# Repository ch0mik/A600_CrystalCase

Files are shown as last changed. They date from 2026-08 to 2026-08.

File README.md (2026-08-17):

# A600Reborn + PiStorm16 CM4 acrylic enclosure

[Polska wersja](CZYTAJTO.md)

Flat CNC-cut enclosure panels for an Amiga 600 motherboard compatible with the
[A600Reborn](https://github.com/istedman/A600Reborn) project, a PiStorm16/CM4
with active cooling, a bottom-mounted 1 MB Chip RAM expansion and a
FrameThrower 600. Video is exposed through a full-size HDMI ribbon adapter and
bracket installed in place of the RF modulator.

> **Disclaimer:** This is an experimental, unverified mechanical design. I
> accept no responsibility for damage to equipment, data loss, injury, or any
> other loss resulting from its manufacture, assembly, or use. You build and
> use it entirely at your own risk. Verify every dimension, clearance, wiring
> connection, and electrical polarity on your own hardware before power-up.

> **Status: mechanical prototype.** The motherboard outline and connector
> positions come from KiCad, but no manufacturing drawings are publicly
> available for the HDMI bracket, Ami64 Gotek assembly or the exact CM4 cooler.
> Before cutting the final acrylic, make a test I/O panel from 1 mm cardboard
> or HDF and verify the dimensions listed below.

## Repository contents

```text
.
├── dxf_screws/          screw-fastened CNC files at 1:1 scale
├── dxf_simple_joinery/  simple Bramble Pi-style finger-joint variant
├── generate_dxf.py      dependency-free parametric generator
├── visualize_assembly.py deterministic DXF/KiCad 3D projection
├── renders/             generated SVG and PNG assembly views
├── .gitignore
├── README.md            English documentation
└── CZYTAJTO.md          Polish documentation
```

The generated DXF files are intentionally committed so they can be sent to a
manufacturer without installing Python. After changing parameters, regenerate
them with:

```powershell
python generate_dxf.py
```

The technical views in `renders/` are generated deterministically from the DXF
and source PCB rather than by an image generator. Rebuild both views with:

```powershell
python visualize_assembly.py --pcb C:\path\to\Amiga600.kicad_pcb
```

The command rebuilds both views of the finger-joint enclosure.

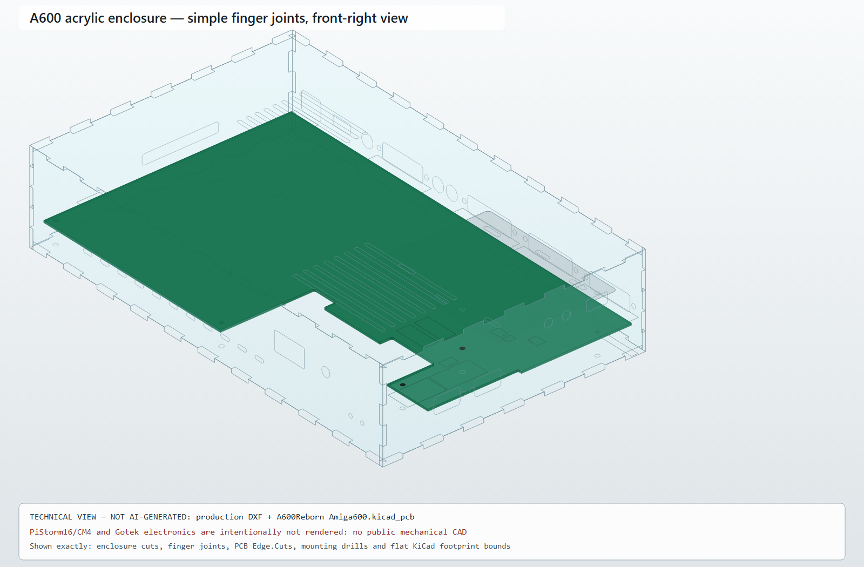
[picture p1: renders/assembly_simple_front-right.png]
Front-right assembly preview


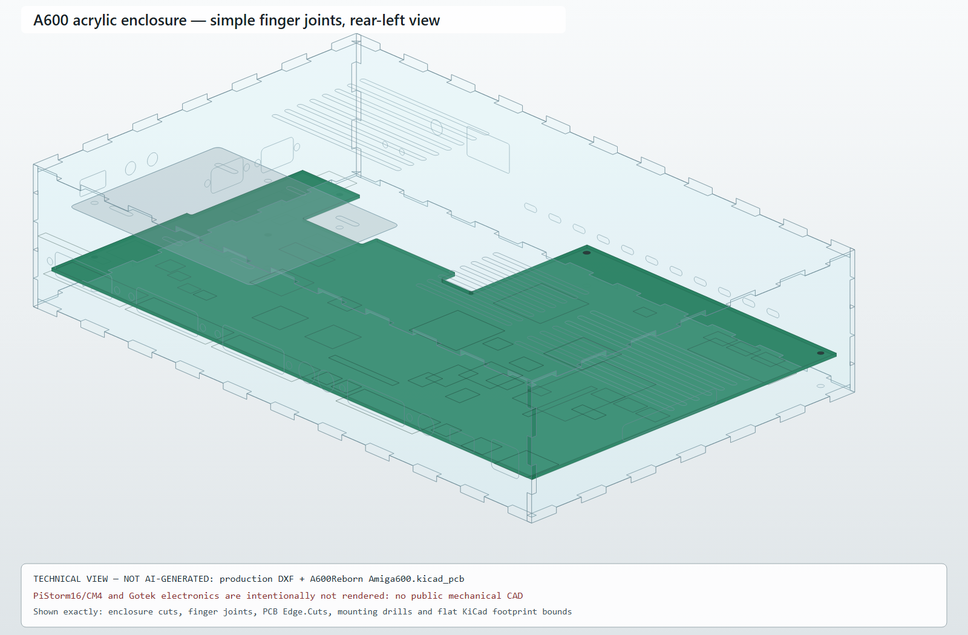
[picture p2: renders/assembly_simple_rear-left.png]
Rear-left assembly preview


> **AI disclosure:** The conceptual photorealistic image below was generated
> by AI from the supplied assembled A600 photo. It is visibly labelled in the
> image in line with the transparency principle described in the
> [European Commission's AI regulatory framework](https://digital-strategy.ec.europa.eu/en/policies/regulatory-framework-ai).

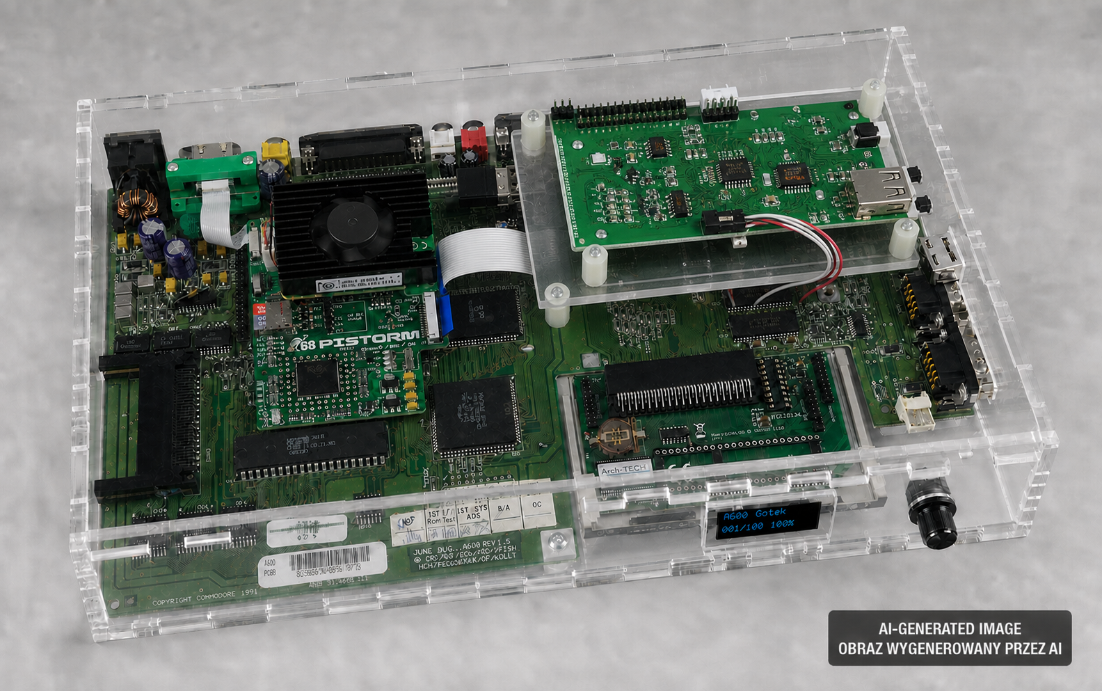
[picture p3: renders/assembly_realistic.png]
AI-generated conceptual photorealistic enclosure preview


The AI-generated image is illustrative only. It shows the requested bare Gotek
PCB on a carrier, with its USB and buttons at the right wall and the 0.96-inch
OLED/encoder at the front. Use the non-AI SVG/DXF technical views for dimensions
and manufacturing decisions.

Only geometry confirmed by the DXF/KiCad sources is shown. The PCB `Edge.Cuts`,
mounting-drill diameters and flat footprint bounds are read directly from the
KiCad file. No arbitrary component heights are assigned. PiStorm16/CM4 and
Gotek electronics are deliberately omitted because no public mechanical CAD
is available; the visualizer does not replace them with invented models.

## Production files

The `dxf_screws/` directory contains the screw-fastened variant:

- `01_bottom_3mm.dxf` — bottom plate, five motherboard mounting points and
  ventilation below the RAM expansion;
- `01b_bottom_gotek_3mm.dxf` — compatible Gotek bottom; the carrier shares
  motherboard H1/MT6 standoff axes and needs no extra bottom holes;
- `02_top_3mm.dxf` — top plate with PiStorm16 intake and exhaust ventilation;
- `02b_top_gotek_oled_rotary_3mm.dxf` — top with a 0.96-inch OLED window,
  rotary encoder and activity LED;
- `02c_top_gotek_external_box_3mm.dxf` — top with two ribbon-cable passages for
  the Ami64 external display box;
- `02d_top_gotek_carrier_above_cn11_3mm.dxf` — unpierced top for a Gotek
  mounted above CN11 on motherboard standoffs;
- `03_rear_io_1mm.dxf` — power, HDMI, composite, RGB, audio, serial, parallel
  and external floppy ports;
- `04_right_io_3mm.dxf` — two DE-9 mouse/joystick ports;
- `04b_right_io_floppy_3mm.dxf` — alternative side panel with a generic floppy
  drive opening;
- `04c_right_io_gotek_usb_3mm.dxf` — Gotek side panel with rear-positioned
  USB-A access and two 6.5 mm control-button openings;
- `05_left_pcmcia_3mm.dxf` — PCMCIA opening;
- `06_front_3mm.dxf` — ventilated front panel with two 3 mm LED openings;
- `06b_front_gotek_oled_rotary_3mm.dxf` — front panel with the 0.96-inch OLED
  and rotary encoder;
- `07_gotek_carrier_3mm.dxf` — adjustable carrier for the bare Gotek PCB.

The files use ASCII AutoCAD R12 DXF, **millimetres**, and **1:1 scale**. Every
production file contains closed contours on the `CUT` layer only. Tool-radius
compensation is not included and must be applied on the correct side of each
contour in CAM.

All Ø3.4 mm M3 holes are **clearance holes**, not threads. Neither 1 mm nor
3 mm acrylic is thick enough to retain an M3 thread reliably. Use through
bolts with nuts and washers, threaded metal/nylon standoffs, or corner blocks.
Never drive an M3 screw directly into an acrylic panel. The 1 mm rear panel
also requires load-spreading washers and support from a bracket or standoff;
do not countersink the 1 mm sheet.

## Dimensions and assembly

- horizontal plate envelope: 329 × 206 mm;
- vertical panel height: 72 mm;
- top, bottom and side panels: 3 mm acrylic;
- rear I/O panel: 1 mm PETG or polycarbonate is safer than brittle 1 mm PMMA;
- motherboard underside: 18 mm above the bottom plate, using nylon M3
  standoffs;
- top/bottom corner standoffs: four M3 × 72 mm;
- H1–H3 mounting points: M3 screws installed without stressing the PCB;
- MT5–MT6 mounting points: M3 screws with insulating washers.

MT1–MT4 are intentionally unused. They are 3.75 × 1.50 mm slots on the PCB,
not M3 mounting holes. MT7 is not drilled through. H1–H3 and MT5–MT6 provide
five stable mounting points without modifying the motherboard.

Standard, current front-mounted OLED/encoder, and legacy top-ribbon variants
are provided. The carrier in `dxf_screws/07_gotek_carrier_3mm.dxf` is shared by all
enclosure construction methods.

## Simple finger-joint variant

The `dxf_simple_joinery/` directory contains a simpler design inspired by the
[BRAMBLE Pi case](https://www.tindie.com/products/Nick/bramble-pi-raspberry-pi-case/).
Its six panels press together directly with complementary rectangular fingers;
there are no separate through-tenons or locking wedges. All I/O openings and
the standard and two Gotek configurations are retained.

Every wall, including the rear panel, uses **3 mm** sheet. Fingers are roughly
16 mm wide and the generator gives each finger/recess pair 0.12 mm total
clearance (`SIMPLE_FINGER_CLEARANCE`). Treat this as a starting value: cut a
small fit sample from the production sheet and tune it for the actual kerf.
Sharp internal corners suit laser cutting; add dog-bones in CAM when routing.

Rear-panel orientation is stated from the user's position in front of the
Amiga: the power inlet is on the left (small X coordinate).

## Ami64 OLED + Rotary Gotek variant

The current arrangement uses panels `01`, `02d`, `04c`, `06b`, and carrier `07`.
The Gotek carrier sits above floppy connector CN11 in the motherboard's rear
right area. Longer nylon standoffs share the motherboard H1 and MT6 mounting
axes, so neither the top nor bottom receives separate carrier holes. The
0.96-inch OLED and rotary encoder are installed in the right side of the front
panel.

The OLED window is 28 × 15 mm and the encoder-bushing hole is 7.5 mm. The
`04c` panel provides a 16.5 × 8.5 mm USB-A opening and two 6.5 mm button holes
on the right wall, between the rear and the DE-9 ports. The 120 × 95 mm carrier
is a separate laser-cut mounting element for the **bare, enclosure-less Gotek
PCB** shown in the [supplied product reference](https://www.simulant.uk/shop/image/cache/catalog/Product%20Images/RETRO/amiga/amiga1200-gotek-full-kit-750x750.jpg).
Install the Gotek component-side up on four nylon M3 standoffs, with USB and
both buttons toward the right wall. Its four horizontal slots allow X-axis
adjustment for different PCB revisions; the two carrier-to-motherboard holes
share the H1 and MT6 axes. The product photo has no dimensional scale and the
manufacturer does not publish a manufacturing drawing, so measure the actual
PCB hole pitch, connector centres, overall height, and standoff clearance
before CNC. Edit the `GOTEK_*` parameters in `generate_dxf.py` if needed.

Vertical panels in the screw-fastened version may be attached using 15 × 15 mm
angle brackets or 3D-printed corner blocks. Corner holes are Ø3.4 mm clearance
holes for M3 through-bolts; the nut or thread belongs in the bracket/standoff,
never in 1 or 3 mm acrylic. Do not glue the panels before a trial assembly and
D-sub plug-clearance check.

## HDMI and FrameThrower

The design assumes the Archi-TECH kit containing a full-size HDMI connector
PCB, flex cable, mini-HDMI connector and printed bracket fitted in place of the
RF modulator. The rear panel has a 16.0 × 7.5 mm aperture centred on the
A600Reborn X2/RF position. The bracket remains attached to the motherboard;
the thin rear panel acts only as a bezel.

FrameThrower 600 clips onto Denise and connects to the PiStorm through CSI, so
it does not require a separate enclosure opening.

## Checks required before machining

The motherboard and port geometry comes from the source
`Amiga600.kicad_pcb`. Mechanical drawings are not published for every floppy
drive, HDMI bracket, RAM expansion or Gotek revision. Make a trial rear panel
from 1 mm cardboard or HDF and verify:

1. Connector centre height — this design uses 26.6 mm from the lower panel
   edge in the screw-fastened variant.
2. The 16.0 × 7.5 mm HDMI aperture and its centre position.
3. At least 15 mm clearance below the motherboard for the RAM expansion.
4. Floppy slot position before using the `04b` panel.
5. Gotek USB position and encoder-bushing diameter before using `02b`/`04c`.
6. Actual acrylic thickness with callipers before cutting the finger joints.

If measurements differ, edit `PCB_Z`, `IO_Z`, `SIMPLE_FINGER_CLEARANCE`, or the relevant
opening parameters in `generate_dxf.py`, then run `python generate_dxf.py`.

## Dimensional sources

- [A600Reborn](https://github.com/istedman/A600Reborn), KiCad PCB and connector
  footprints: maximum outline 316.992 × 194.056 mm;
- H1 `(311.912; 22.352)`, H2 `(5.080; 188.976)`, H3
  `(282.956; 150.622)`, MT5 `(158.496; 187.960)`, and MT6
  `(274.066; 96.393)` relative to the PCB origin;
- [PiStorm16 CM4](https://programatory.archi-tech.com.pl/pl/p/Pistorm16-RPi-CM4-Gotowy-do-pracy/359)
  — active cooling and ribbon-mounted HDMI;
- [HDMI bracket replacing RF](https://programatory.archi-tech.com.pl/pl/p/Mocowanie-portu-HDMI-w-miejscu-modulatora-Amiga-600/354);
- [FrameThrower 600](https://programatory.archi-tech.com.pl/pl/p/Framethrower-600-FT600-Pistorm/375)
  — Denise mounting and CSI connection;
- [Ami64 OLED + Rotary Gotek](https://www.ami64.com/product-page/internal-amiga-a600-gotek-with-oled-rotary)
  — internal floppy emulator and external 0.96-inch OLED/encoder unit.

## Manufacturing notes

- Apply cutter compensation toward the waste side; DXFs do not include tool
  compensation.
- Use a single-flute plastic-cutting bit for acrylic and leave the protective
  film attached while machining.
- PETG or polycarbonate is preferable to brittle PMMA for the 1 mm rear panel.
- Use nylon screws or insulating washers near the motherboard.
- Never connect a second power supply to the Raspberry Pi/PiStorm while the
  Amiga is also supplying power.

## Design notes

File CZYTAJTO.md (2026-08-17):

# Obudowa plexi A600Reborn + PiStorm16 CM4

[English version](README.md)

Zestaw płaskich paneli CNC dla płyty Amiga 600 zgodnej z projektem
[A600Reborn](https://github.com/istedman/A600Reborn), PiStorm16/CM4 z aktywnym
chłodzeniem, dolnego rozszerzenia 1 MB Chip RAM oraz FrameThrower 600. Wyjście
obrazu stanowi pełnowymiarowe HDMI na taśmie i uchwycie montowanym w miejscu
modulatora RF.

> **Zastrzeżenie:** To eksperymentalny, niezweryfikowany projekt mechaniczny.
> Nie odpowiadam za uszkodzenie sprzętu, utratę danych, obrażenia ani inne
> szkody powstałe podczas wykonania, montażu lub użytkowania. Wykonujesz i
> używasz go wyłącznie na własne ryzyko. Przed włączeniem zasilania samodzielnie
> sprawdź wszystkie wymiary, luzy, połączenia oraz polaryzację zasilania.

> **Status: prototyp mechaniczny.** Geometria płyty i złączy pochodzi z KiCad,
> ale uchwyt HDMI, Gotek Ami64 i konkretne chłodzenie CM4 nie mają publicznych
> rysunków wykonawczych. Przed cięciem docelowej plexi wykonaj próbny panel I/O
> z HDF lub kartonu 1 mm i sprawdź wymiary opisane niżej.

## Zawartość repozytorium

```text
.
├── dxf_screws/          wariant skręcany, pliki CNC w skali 1:1
├── dxf_simple_joinery/  prosty wariant finger-joint w stylu Bramble Pi
├── generate_dxf.py      parametryczny generator bez zależności zewnętrznych
├── visualize_assembly.py deterministyczny rzut 3D z DXF i KiCad
├── renders/             wygenerowane widoki SVG i PNG
├── .gitignore
├── README.md            dokumentacja angielska
└── CZYTAJTO.md          dokumentacja polska
```

Pliki w `dxf_screws/` są celowo przechowywane w repozytorium, żeby można było wysłać
je do wykonawcy bez instalowania Pythona. Po zmianie parametrów wygeneruj je
ponownie poleceniem:

```powershell
python generate_dxf.py
```

Wizualizacje techniczne w `renders/` są generowane deterministycznie z DXF i
źródłowego PCB — nie przez generator obrazów. Aby odtworzyć oba widoki:

```powershell
python visualize_assembly.py --pcb C:\ścieżka\do\Amiga600.kicad_pcb
```

Polecenie odtwarza oba widoki obudowy finger-joint.

Podgląd z przodu i prawej

Podgląd z tyłu i lewej

> **Informacja o AI:** Poniższy koncepcyjny obraz fotorealistyczny został
> wygenerowany przez AI na podstawie dostarczonego zdjęcia złożonej A600.
> Oznaczenie jest widoczne bezpośrednio na obrazie, zgodnie z zasadą
> przejrzystości opisaną w
> [ramach regulacyjnych AI Komisji Europejskiej](https://digital-strategy.ec.europa.eu/pl/policies/regulatory-framework-ai).

Wygenerowany przez AI fotorealistyczny podgląd obudowy

Obraz wygenerowany przez AI jest wyłącznie ilustracją. Pokazuje zamówioną nagą
płytkę Goteka na nośniku, USB i przyciski na prawym boku oraz OLED 0,96 cala z
enkoderem na froncie. Przy wymiarowaniu i produkcji należy korzystać z
niegenerowanych przez AI widoków SVG oraz plików DXF.

Skrypt pokazuje wyłącznie geometrię potwierdzoną w DXF/KiCad. Obrys PCB
`Edge.Cuts`, średnice otworów montażowych i płaskie granice footprintów są
odczytywane bezpośrednio z pliku KiCad. Nie są nadawane umowne wysokości
elementów. PiStorm16/CM4 i elektronika Goteka są świadomie pominięte, ponieważ
nie ma ich publicznych rysunków mechanicznych; nie są zastępowane wymyślonymi
modelami.

## Pliki do produkcji

W katalogu `dxf_screws/` znajduje się wariant skręcany:

- `01_bottom_3mm.dxf` — dno, pięć punktów montażowych PCB i nawiew pod RAM;
- `01b_bottom_gotek_3mm.dxf` — zgodne dno wariantu Gotek; nośnik korzysta z
  osi dystansów płyty H1/MT6, więc nie wymaga dodatkowych otworów w dnie;
- `02_top_3mm.dxf` — góra, nawiew PiStorm16 i wylot po przeciwnej stronie;
- `02b_top_gotek_oled_rotary_3mm.dxf` — góra z OLED-em 0,96 cala,
  enkoderem i diodą aktywności;
- `02c_top_gotek_external_box_3mm.dxf` — góra z dwoma przepustami taśm,
  zgodna z zewnętrznym pudełkiem dostarczanym przez Ami64;
- `02d_top_gotek_carrier_above_cn11_3mm.dxf` — pełna góra dla Goteka
  zamontowanego nad CN11 na dystansach płyty;
- `03_rear_io_1mm.dxf` — zasilanie, HDMI, composite, RGB, audio, serial,
  parallel i external floppy;
- `04_right_io_3mm.dxf` — dwa porty joystick/mouse DE-9;
- `04b_right_io_floppy_3mm.dxf` — alternatywa z ogólnym otworem napędu;
- `04c_right_io_gotek_usb_3mm.dxf` — panel Goteka z USB-A w tylnej strefie
  oraz dwoma otworami 6,5 mm na przyciski sterujące;
- `05_left_pcmcia_3mm.dxf` — PCMCIA;
- `06_front_3mm.dxf` — front z wentylacją i dwiema diodami 3 mm;
- `06b_front_gotek_oled_rotary_3mm.dxf` — front z OLED-em 0,96 cala i
  enkoderem;
- `07_gotek_carrier_3mm.dxf` — regulowany nośnik nagiej płytki PCB Goteka.

DXF jest w formacie ASCII AutoCAD R12, jednostki: **mm**, skala **1:1**. Każdy
plik produkcyjny zawiera wyłącznie zamknięte kontury na warstwie `CUT`. Nie ma
kompensacji średnicy frezu — operator CAM powinien ustawić ją po właściwej
stronie konturu.

Wszystkie otwory Ø3,4 mm pod M3 są **otworami przelotowymi**, a nie gwintami.
Plexi 1 mm ani 3 mm nie utrzyma pewnie gwintu M3. Należy stosować śruby
przelotowe z nakrętkami i podkładkami, gwintowane dystanse metalowe/nylonowe
albo kostki narożne. Nie wolno wkręcać M3 bezpośrednio w plexi. Panel tylny
1 mm wymaga również podkładek rozkładających nacisk i podparcia kątownikiem
lub dystansem; nie należy go pogłębiać pod łeb stożkowy.

## Wymiary i montaż

- gabaryt zewnętrzny płyt poziomych: 329 × 206 mm;
- wysokość paneli pionowych: 72 mm;
- góra, dół i boki: plexi 3 mm;
- tył I/O: PETG/poliwęglan 1 mm jest bezpieczniejszy od kruchej plexi 1 mm;
- spód PCB: 18 mm nad dnem, dystanse nylonowe M3;
- płyty góra/dół: cztery dystanse narożne M3, długość 72 mm;
- otwory w H1–H3: śruba M3 bez naprężania PCB;
- otwory MT5–MT6: śruba M3 z podkładką izolacyjną.

Nie użyto MT1–MT4: na PCB są to szczeliny 3,75 × 1,50 mm, a nie otwory pod
M3. MT7 nie ma przewiercenia. Pięć zastosowanych punktów daje stabilne podparcie
bez przerabiania płyty.

Dostępne są wersje zwykła, aktualna z OLED-em/enkoderem we froncie oraz starsze
warianty prowadzenia przewodów przez pokrywę. Nośnik Goteka
`dxf_screws/07_gotek_carrier_3mm.dxf` jest wspólny dla wszystkich sposobów łączenia.

## Proste połączenia finger-joint

Katalog `dxf_simple_joinery/` zawiera prostszą wersję wzorowaną na
[obudowie BRAMBLE Pi](https://www.tindie.com/products/Nick/bramble-pi-raspberry-pi-case/).
Sześć płyt łączy się bez dodatkowych klinów: prostokątne palce na każdej
krawędzi wchodzą bezpośrednio w komplementarne wycięcia sąsiedniej płyty.
Zachowano wszystkie otwory I/O oraz zwykłe i oba warianty Goteka.

Wszystkie ściany, łącznie z tylną, są przeznaczone na arkusz **3 mm**. Palce
mają około 16 mm szerokości, a generator dodaje 0,12 mm całkowitego luzu na
parę palec–wycięcie (`SIMPLE_FINGER_CLEARANCE`). Jest to wartość startowa:
przed cięciem kompletu wykonaj próbę na kilku palcach z tego samego arkusza i
dopasuj luz do rzeczywistego kerfu. Ostre narożniki są przeznaczone przede
wszystkim do lasera; przy frezowaniu trzeba dodać dog-bones w CAM.

Orientacja panelu tylnego jest podana względem użytkownika stojącego przed
Amigą: gniazdo zasilania znajduje się po lewej stronie (mała współrzędna X).

### Wariant Gotek Ami64 OLED + Rotary

Aktualny układ używa paneli `01`, `02d`, `04c`, `06b` i nośnika `07`. Nośnik
Goteka znajduje się nad złączem floppy CN11 w prawym tylnym obszarze płyty.
Jest przykręcony na dłuższych nylonowych dystansach współosiowych z punktami
montażowymi motherboardu H1 i MT6; pokrywa i dno nie dostają osobnych otworów.
OLED 0,96 cala oraz enkoder są zamontowane w prawej części panelu przedniego.

Okno OLED ma 28 × 15 mm, a otwór tulei enkodera 7,5 mm. Panel `04c` ma na
prawym boku, między tyłem a gniazdami DE-9, otwór USB-A 16,5 × 8,5 mm i dwa
otwory 6,5 mm na przyciski. Nośnik 120 × 95 mm jest osobnym elementem wycinanym
laserowo dla **nagiej płytki Goteka, bez fabrycznej obudowy**, pokazanej na
[podanym zdjęciu produktu](https://www.simulant.uk/shop/image/cache/catalog/Product%20Images/RETRO/amiga/amiga1200-gotek-full-kit-750x750.jpg).
Płytkę należy zamontować elementami do góry na czterech nylonowych dystansach
M3, kierując USB i oba przyciski ku prawej ścianie. Cztery podłużne otwory
pozwalają korygować rozstaw w osi X, a dwa otwory nośnika pokrywają się z osiami
H1 i MT6 płyty głównej. Zdjęcie produktu nie ma skali, a producent nie publikuje
rysunku wykonawczego, dlatego przed CNC trzeba zmierzyć rzeczywisty rozstaw
otworów PCB, środki złączy, całkowitą wysokość oraz prześwit nad płytą. W razie
potrzeby należy zmienić parametry `GOTEK_*` w `generate_dxf.py`.

Panele pionowe wariantu skręcanego najlepiej łączyć z płytami kątownikami
15 × 15 mm albo kostkami drukowanymi 3D. Otwory narożne Ø3,4 mm są wyłącznie
przelotowe; nakrętka lub gwint musi znajdować się w kątowniku/dystansie, nigdy
w plexi 1 lub 3 mm. Nie kleić boków przed próbnym złożeniem i sprawdzeniem
wtyków D-sub.

## HDMI i FrameThrower

Projekt zakłada zestaw Archi-TECH: pełne HDMI na PCB, taśma flex, mini-HDMI i
drukowany uchwyt mocowany w miejscu RF. Panel ma otwór 16,0 × 7,5 mm ze środkiem
zgodnym z położeniem X2/RF projektu A600Reborn. Uchwyt pozostaje przykręcony do
płyty; cienki panel tylny pełni tylko rolę maskownicy. FrameThrower 600 zakłada
się na Denise i łączy z PiStorm przez CSI — nie wymaga osobnego otworu.

## Ważne przed frezowaniem

Geometria płyty i portów pochodzi ze źródłowego `Amiga600.kicad_pcb`. Mechanika
konkretnego napędu dyskietek, uchwytu HDMI i wariantu rozszerzenia RAM nie jest
opublikowana jako rysunek wymiarowy. Dlatego najpierw wykonaj próbny tył z
kartonu/HDF 1 mm i sprawdź:

1. wysokość osi złączy — projekt: 26,6 mm od dolnej krawędzi panelu;
2. otwór HDMI 16,0 × 7,5 mm i jego środek;
3. czy RAM ma co najmniej 15 mm luzu pod PCB;
4. położenie szczeliny napędu przed użyciem wariantu `04b`.
5. położenie USB i średnicę gwintowanej tulei enkodera przed użyciem `02b/04c`.

Jeżeli pomiar różni się od założenia, zmień `PCB_Z`, `IO_Z` albo parametry
danego otworu w `generate_dxf.py` i uruchom `python generate_dxf.py`.

## Źródła wymiarów

- [A600Reborn](https://github.com/istedman/A600Reborn), plik KiCad i footprinty
  złączy: obrys 316,992 × 194,056 mm;
- H1 `(311,912; 22,352)`, H2 `(5,080; 188,976)`, H3
  `(282,956; 150,622)`, MT5 `(158,496; 187,960)`, MT6
  `(274,066; 96,393)` — współrzędne względem PCB;
- [PiStorm16 CM4](https://programatory.archi-tech.com.pl/pl/p/Pistorm16-RPi-CM4-Gotowy-do-pracy/359)
  — aktywne chłodzenie oraz HDMI na taśmie;
- [uchwyt HDMI zamiast RF](https://programatory.archi-tech.com.pl/pl/p/Mocowanie-portu-HDMI-w-miejscu-modulatora-Amiga-600/354);
- [FrameThrower 600](https://programatory.archi-tech.com.pl/pl/p/Framethrower-600-FT600-Pistorm/375)
  — montaż na Denise i połączenie CSI;
- [Gotek Ami64 OLED + Rotary](https://www.ami64.com/product-page/internal-amiga-a600-gotek-with-oled-rotary)
  — wewnętrzny emulator stacji oraz zewnętrzny OLED 0,96 cala z enkoderem.

## Uwagi produkcyjne

- frez powinien wejść od strony odpadu; DXF nie zawiera kompensacji narzędzia;
- dla plexi stosuj frez jednopiórowy do tworzyw i nie zdejmuj folii ochronnej;
- panel tylny 1 mm lepiej wykonać z PETG lub poliwęglanu niż kruchego PMMA;
- śruby przy PCB powinny być nylonowe albo mieć podkładki izolacyjne;
- nie podłączaj dodatkowego zasilacza do Raspberry Pi/PiStorm równolegle z
  zasilaniem Amigi.

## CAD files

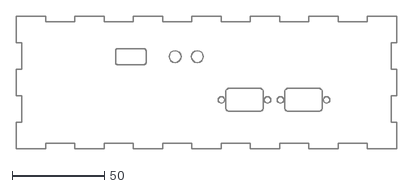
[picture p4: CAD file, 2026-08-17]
dxf_simple_joinery/04c_right_io_simple_gotek_usb_3mm.dxf
206.0 x 72.0

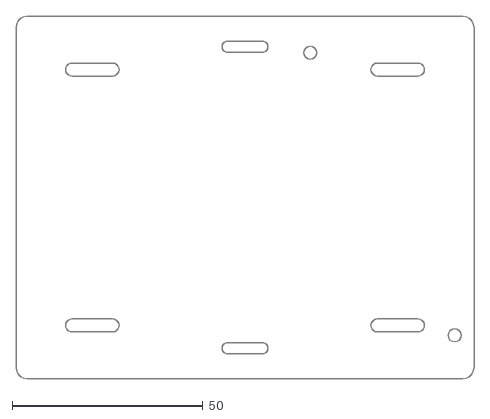
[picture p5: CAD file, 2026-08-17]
dxf_simple_joinery/07_gotek_carrier_3mm.dxf
120.0 x 95.0

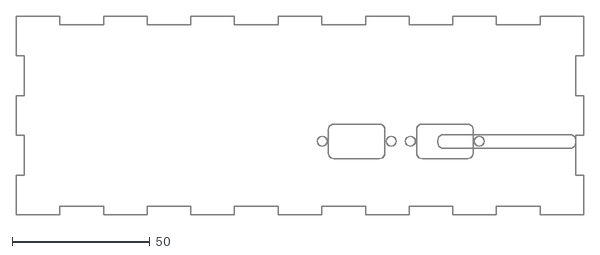
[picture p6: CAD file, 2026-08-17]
dxf_simple_joinery/04b_right_io_simple_floppy_3mm.dxf
206.0 x 72.0

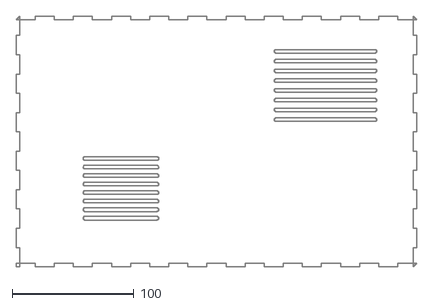
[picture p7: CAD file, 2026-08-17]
dxf_simple_joinery/02_top_simple_3mm.dxf
329.0 x 206.0

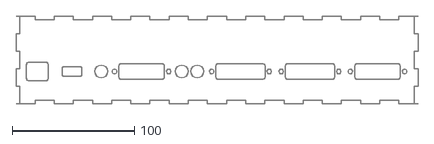
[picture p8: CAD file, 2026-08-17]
dxf_simple_joinery/03_rear_io_simple_3mm.dxf
329.0 x 72.0

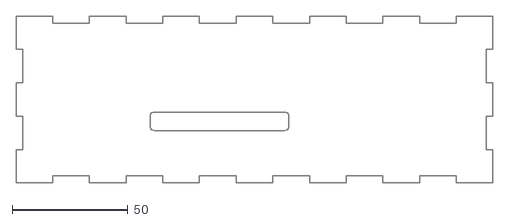
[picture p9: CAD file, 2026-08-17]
dxf_simple_joinery/05_left_pcmcia_simple_3mm.dxf
206.0 x 72.0

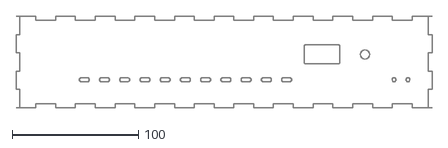
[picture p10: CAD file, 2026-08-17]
dxf_simple_joinery/06b_front_simple_gotek_oled_rotary_3mm.dxf
329.0 x 72.0

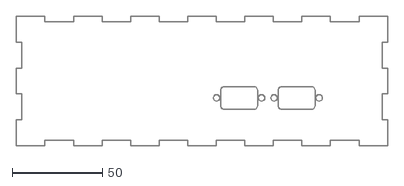
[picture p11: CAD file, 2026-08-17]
dxf_simple_joinery/04_right_io_simple_3mm.dxf
206.0 x 72.0

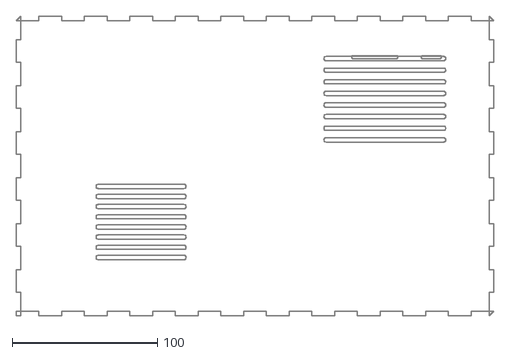
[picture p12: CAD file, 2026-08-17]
dxf_simple_joinery/02c_top_simple_gotek_external_box_3mm.dxf
329.0 x 206.0

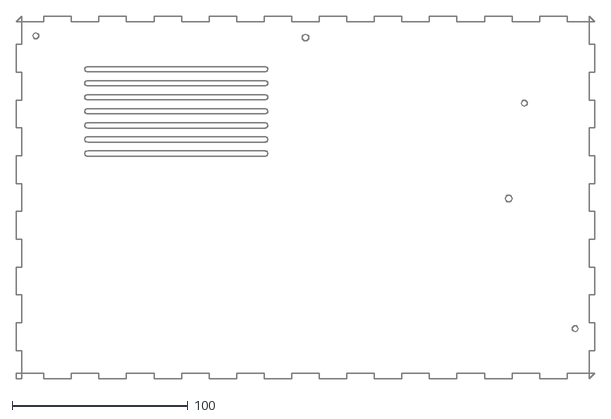
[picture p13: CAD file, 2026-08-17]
dxf_simple_joinery/01_bottom_simple_3mm.dxf
329.0 x 206.0

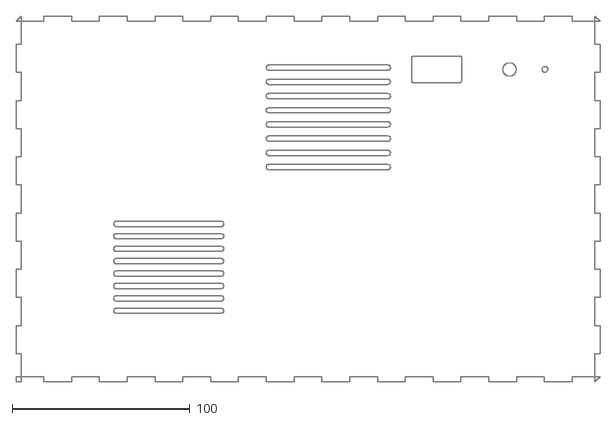
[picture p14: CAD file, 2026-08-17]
dxf_simple_joinery/02b_top_simple_gotek_oled_rotary_3mm.dxf
329.0 x 206.0

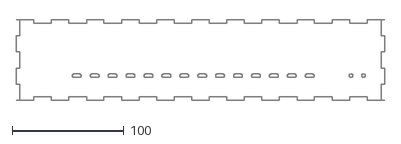
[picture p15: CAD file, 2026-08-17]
dxf_simple_joinery/06_front_simple_3mm.dxf
329.0 x 72.0

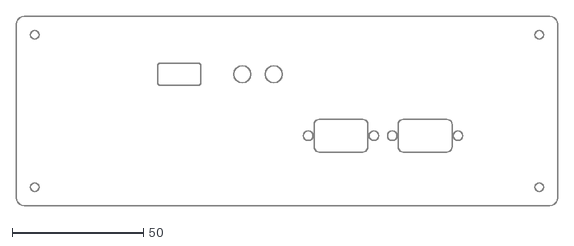
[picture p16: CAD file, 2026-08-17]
dxf_screws/04c_right_io_gotek_usb_3mm.dxf
206.0 x 72.0

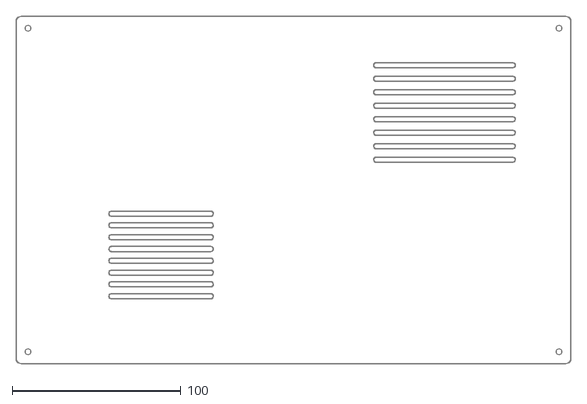
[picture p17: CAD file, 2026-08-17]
dxf_screws/02_top_3mm.dxf
329.0 x 206.0

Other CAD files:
dxf_screws/04_right_io_3mm.dxf
dxf_screws/01_bottom_3mm.dxf
dxf_screws/01b_bottom_gotek_3mm.dxf
dxf_screws/02b_top_gotek_oled_rotary_3mm.dxf
dxf_screws/02c_top_gotek_external_box_3mm.dxf
dxf_screws/03_rear_io_1mm.dxf
dxf_screws/04b_right_io_floppy_3mm.dxf
dxf_screws/05_left_pcmcia_3mm.dxf
dxf_screws/06_front_3mm.dxf
dxf_screws/06b_front_gotek_oled_rotary_3mm.dxf
